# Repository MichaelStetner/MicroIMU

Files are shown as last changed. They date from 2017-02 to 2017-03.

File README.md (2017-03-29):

# MicroIMU
Gryo, accelerometer, and compass on a very small PCB

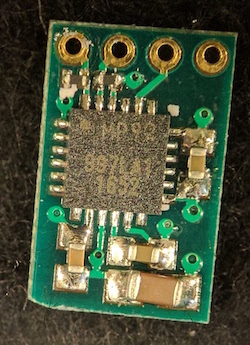
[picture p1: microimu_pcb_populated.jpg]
MicroIMU Populated PCB


This project is inspired by [Pololu's MinIMU](https://www.pololu.com/product/2738). We redesigned  The design was changed for our particular application: simultaneous recording of neural activity and body movements. To record body movements, the MicroIMU is attached to an animal. To minimize the animal's discomfort, the MicroIMU needs to be as small and light as possible.
Alongside the MicroIMU, neural activity is recorded with sensitive analog electronics (not included in this repository). To protect the analog electronics, they must be shielded from intereference coming from the digital signals on the MicroIMU so the PCB contains power and ground planes.

Compared to MinIMU, MicroIMU has the following improvements:
* Smaller board size
* Reduced weight
* Power and ground planes
* Wider input voltage range: 2.5V-30V, up from 2.5V-5.5V

Here are the ways that this MicroIMU is less desirable than Pololu's MinIMU:
* 4 PCB layers, up from 2 (increases manufacturing cost)
* 3.3V I2C communication, down from 5V (compatible with Arduino Due, but not Arduino Uno)
* Less stable power supply (fewer bypass capacitors)
* No external connections for VDD (3.3V) or SA0 (least significant bit of I2C address)

### Acknowledgements
* EAGLE libraries from openrobots-dev/Eagle

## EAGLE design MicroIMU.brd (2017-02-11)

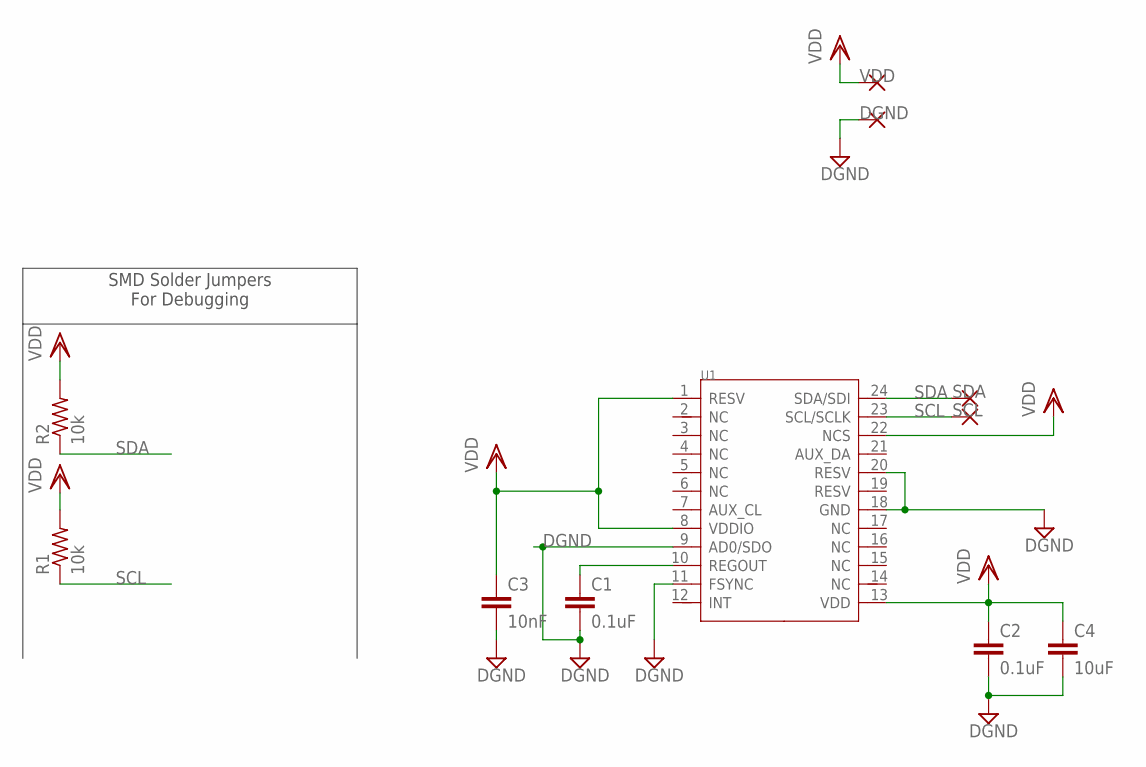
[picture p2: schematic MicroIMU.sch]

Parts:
C1, C2: 0.1uF; C0402
C3: 10nF; C0402
C4: 10uF; C0603
DGND: THROUGH-HOLE-30MIL/15MIL; 30MIL/15MIL
R1, R2: 10k; R0201
SCL: THROUGH-HOLE-30MIL/15MIL; 30MIL/15MIL
SDA: THROUGH-HOLE-30MIL/15MIL; 30MIL/15MIL
U1: MPU-9250; LEAD-QFN24
VDD: THROUGH-HOLE-30MIL/15MIL; 30MIL/15MIL

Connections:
DGND: C1.2, C2.2, C3.2, C4.2, DGND.P$1, U1.9 (AD0/SDO), U1.11 (FSYNC), U1.18 (GND), U1.20 (RESV)
unnamed: C1.1, U1.10 (REGOUT)
SCL: R1.1, SCL.P$1, U1.23 (SCL/SCLK)
SDA: R2.1, SDA.P$1, U1.24 (SDA/SDI)
VDD: C2.1, C3.1, C4.1, R1.2, R2.2, U1.1 (RESV), U1.8 (VDDIO), U1.13 (VDD), U1.22 (NCS), VDD.P$1

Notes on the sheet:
SMD Solder Jumpers For Debugging

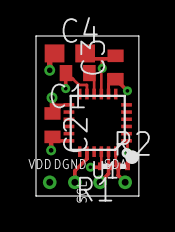
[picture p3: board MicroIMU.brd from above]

Board: 4 copper layers, 5.7 x 8.9 mm, 11 parts (0 on the bottom side), 5 nets.

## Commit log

2015-11-16 Added board and schematic - halfway done with routing
    [MicroIMU.brd, MicroIMU.sch]
2015-11-16 Done routing
    [MicroIMU.brd, MicroIMU.sch]
2015-11-16 Galen made minor layout changes to save space
    [MicroIMU.brd, MicroIMU.sch]
2015-11-16 Added labels to silkscreen layer
    [MicroIMU.brd, MicroIMU.sch]
2015-11-16 Improved silkscreen labels
    [MicroIMU.brd, MicroIMU.sch]
2015-11-16 Galen rearranged the board again - rotated the LSM303DLHC by 90 degrees
    [MicroIMU.brd]
2015-11-16 More rearrangement by Galen - everything is much closer together now
    [MicroIMU.brd, MicroIMU.sch]
2015-11-16 Galen switched to LSM303D for accelerometer/compass - newer design with smaller package
    [MicroIMU.brd, MicroIMU.sch]
2015-11-16 Added missing connections for CS and SA0 on LSM303D
    [MicroIMU.brd, MicroIMU.sch]
2015-11-17 Rotated L3GD20H so that X and Y axes of the two chips are aligned
    [MicroIMU.brd]
2015-11-17 Silkscreen updated
    [MicroIMU.brd]
2017-02-11 changed to invense MPU9250
    [MicroIMU.brd, MicroIMU.sch]
2017-03-12 cleaned up files
    [MicroIMU.brd, MicroIMU.sch]
